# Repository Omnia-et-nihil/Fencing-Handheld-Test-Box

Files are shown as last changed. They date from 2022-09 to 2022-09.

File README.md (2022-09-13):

# Fencing-Handheld-Test-Box
Hardware and software overview: https://youtu.be/j7mpaZ8sDjs  
Functionality overview: https://youtu.be/PdIM2SgSRJE  
    
Assembly notes:  
If you choose to make the housing directly from the included files, you may need to make subtle changes based on the 3d printer/materials used. These were designed for printing on an Anycubic Photon S. 

The screen protector is very slightly to large for the screen opening, so that it may be snapped into place without requiring any other attatchment. It may be 3d printed with clear material using the included stl, or laser cut from clear acrylic using the included svg file.   
  
  The stls for the lid and screen protector include small rounded tabs for easier removal from a resin print plate. They help allow a shim(such as a flexible putty knife) to be slid under the print for relatively easy removal, and then may be easily cut off. 
  
  The tab stencil is an outline you can use to cut out some tabs out of your preferred sheet metal(though it should be uncoated so as to have a conductive surface). Fold the tabs in half around a dowel of some kind, and solder wires to the base before sliding into the slots on the front of the box.

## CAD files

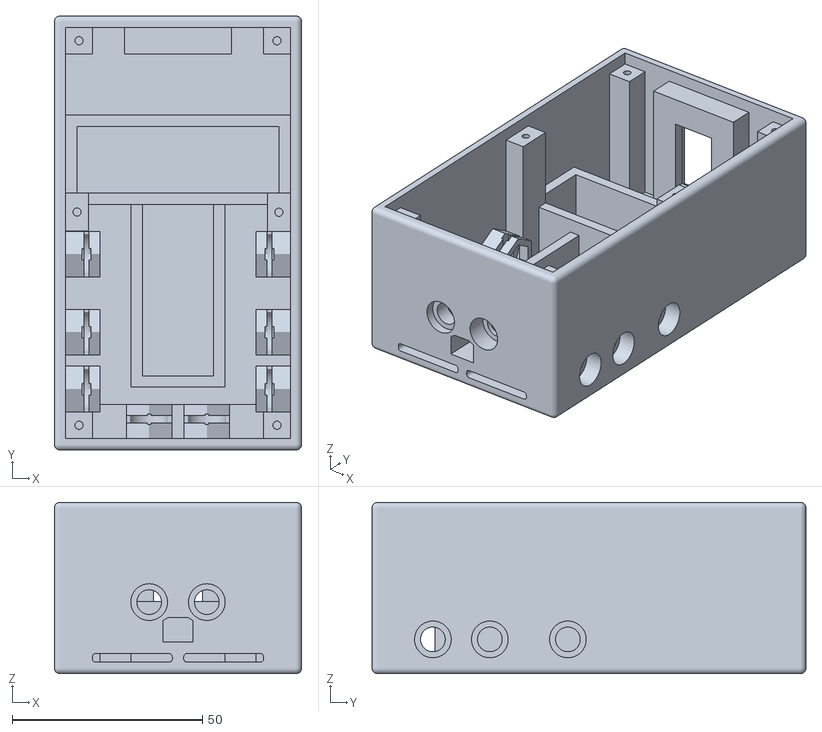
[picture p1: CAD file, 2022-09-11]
test box housing v5.1.stl
65.0 x 114.0 x 45.0

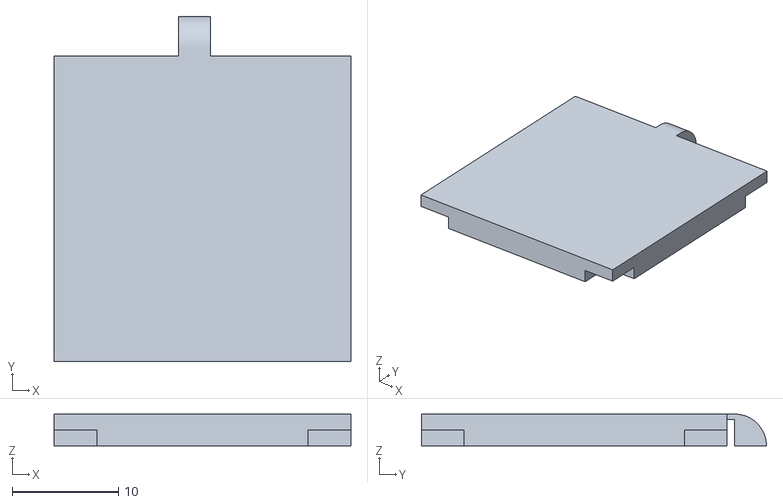
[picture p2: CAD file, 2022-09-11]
test box screen protector v5.1.stl
27.9 x 32.4 x 3.00

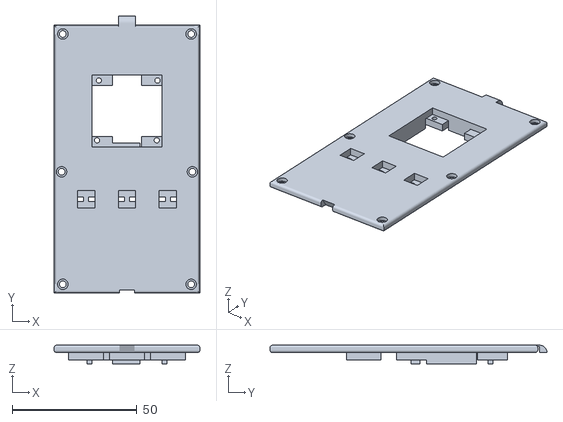
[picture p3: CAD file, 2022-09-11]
test box lid v5.1.stl
58.4 x 111.0 x 7.50

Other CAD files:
fencing test box.f3d

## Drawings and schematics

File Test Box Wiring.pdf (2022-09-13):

tsr | / I / | - socket 4%2^2224 :&"

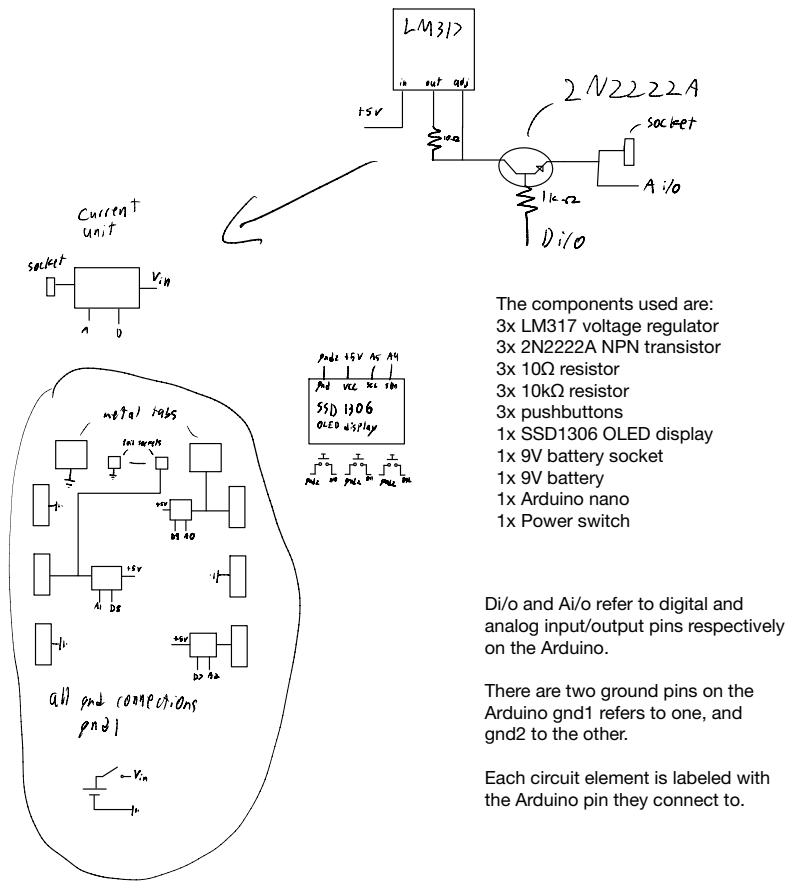
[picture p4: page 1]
out adj; current; unit; Dito; socket; Vin; 9ndzt5VA5A4; VCC; SDA; metal +93s; SSD 1306; 9hdz; gndz.DK; f-Vin

The components used are:
3x LM317 voltage regulator
3x 2N2222A NPN transistor
3x 10Ω resistor
3x 10kΩ resistor
3x pushbuttons
1x SSD1306 OLED display
1x 9V battery socket
1x 9V battery
1x Arduino nano
1x Power switch

OLED display foil sockets

Di/o and Ai/o refer to digital and
analog input/output pins respectively
on the Arduino.

all qnd connections
qndl

There are two ground pins on the
Arduino gnd1 refers to one, and
gnd2 to the other.

Each circuit element is labeled with
the Arduino pin they connect to.

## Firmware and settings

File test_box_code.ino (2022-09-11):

#include <SPI.h>
#include <Wire.h>
#include <Adafruit_GFX.h>
#include <Adafruit_SSD1306.h>
#include <EEPROM.h>

Adafruit_SSD1306 display(128, 64, &Wire, -1);

const unsigned char startGraphic [] PROGMEM = { //Bitmap for the initialization graphic.
  0x00, 0x00, 0x00, 0x00, 0x00, 0x00, 0x01, 0x38, 0x00, 0x00, 0x00, 0x00, 0x00, 0x00, 0x00, 0x00, 
  0x00, 0x00, 0x00, 0x00, 0x00, 0x00, 0x07, 0x78, 0x00, 0x00, 0x00, 0x00, 0x00, 0x00, 0x00, 0x00, 
  0x00, 0x00, 0x00, 0x00, 0x00, 0x00, 0x07, 0x78, 0x00, 0x00, 0x00, 0x00, 0x00, 0x00, 0x00, 0x00, 
  0x00, 0x00, 0x00, 0x00, 0x00, 0x00, 0x07, 0x78, 0x00, 0x00, 0x00, 0x00, 0x00, 0x00, 0x00, 0x00, 
  0x00, 0x00, 0x00, 0x00, 0x00, 0x00, 0x0f, 0x78, 0x00, 0x00, 0x00, 0x00, 0x00, 0x00, 0x00, 0x00, 
  0x00, 0x00, 0x00, 0x00, 0x00, 0x00, 0x0f, 0x78, 0x00, 0x00, 0x00, 0x00, 0x00, 0x00, 0x00, 0x00, 
  0x00, 0x00, 0x00, 0x00, 0x00, 0x00, 0x07, 0x78, 0x00, 0x00, 0x00, 0x00, 0x00, 0x00, 0x00, 0x00, 
  0x00, 0x00, 0x00, 0x00, 0x00, 0x00, 0x07, 0x78, 0x00, 0x00, 0x00, 0x00, 0x00, 0x00, 0x00, 0x00, 
  0x00, 0x00, 0x00, 0x00, 0x00, 0x00, 0x07, 0x78, 0x00, 0x00, 0x00, 0x00, 0x00, 0x00, 0x00, 0x00, 
  0x00, 0x00, 0x00, 0x00, 0x00, 0x00, 0x01, 0x00, 0x00, 0x00, 0x00, 0x00, 0x00, 0x00, 0x00, 0x00, 
  0x00, 0x00, 0x00, 0x00, 0x00, 0x00, 0x00, 0x00, 0x00, 0x00, 0x00, 0x00, 0x00, 0x00, 0x00, 0x00, 
  0x00, 0x00, 0x00, 0x00, 0x00, 0x00, 0x00, 0x00, 0xc0, 0x00, 0x00, 0x00, 0x00, 0x00, 0x00, 0x00, 
  0x00, 0x00, 0x00, 0x00, 0x00, 0x00, 0x00, 0x03, 0xf0, 0x00, 0x00, 0x00, 0x00, 0x00, 0x00, 0x00, 
  0x00, 0x00, 0x00, 0x00, 0x00, 0x0f, 0xfc, 0x07, 0xfc, 0x00, 0x00, 0x00, 0x00, 0x00, 0x00, 0x00, 
  0x00, 0x00, 0x00, 0x03, 0xbf, 0xff, 0xfc, 0x07, 0xff, 0x00, 0x00, 0x00, 0x00, 0x00, 0x00, 0x00, 
  0xff, 0xff, 0xff, 0xff, 0xff, 0xff, 0xfc, 0x07, 0xff, 0x80, 0x00, 0x00, 0x00, 0x00, 0x00, 0x00, 
  0x00, 0x00, 0x00, 0x03, 0xff, 0xff, 0xfe, 0x03, 0xff, 0xe0, 0x00, 0x00, 0x00, 0x00, 0x00, 0x00, 
  0x00, 0x00, 0x00, 0x01, 0x03, 0xff, 0xfe, 0x03, 0xff, 0xf8, 0x00, 0x00, 0x00, 0x00, 0x00, 0x00, 
  0x00, 0x00, 0x00, 0x00, 0x00, 0x00, 0x7e, 0x00, 0xff, 0xfc, 0x00, 0x00, 0x00, 0x00, 0x00, 0x00, 
  0x00, 0x00, 0x00, 0x00, 0x00, 0x00, 0x00, 0x00, 0x1f, 0xff, 0x00, 0x00, 0x00, 0x00, 0x00, 0x00, 
  0x00, 0x00, 0x00, 0x00, 0x00, 0x00, 0x00, 0x00, 0x07, 0xff, 0x80, 0x00, 0x00, 0x00, 0x00, 0x00, 
  0x00, 0x00, 0x00, 0x00, 0x00, 0x00, 0x00, 0x00, 0x00, 0xff, 0xc0, 0x00, 0x00, 0x00, 0x00, 0x00, 
  0x00, 0x00, 0x00, 0x00, 0x00, 0x00, 0x00, 0x00, 0x00, 0x1f, 0xf0, 0x00, 0x00, 0x00, 0x00, 0x00, 
  0x00, 0x00, 0x00, 0x00, 0x00, 0x00, 0x00, 0x00, 0x00, 0x07, 0xf8, 0x00, 0x00, 0x00, 0x00, 0x00, 
  0x00, 0x00, 0x00, 0x00, 0x00, 0x00, 0x00, 0x00, 0x00, 0x01, 0xfc, 0x00, 0x00, 0x00, 0x00, 0x00, 
  0x00, 0x00, 0x00, 0x00, 0x00, 0x00, 0x00, 0x00, 0x00, 0x00, 0x7f, 0x00, 0x00, 0x00, 0x00, 0x00, 
  0x00, 0x00, 0x00, 0x00, 0x00, 0x00, 0x00, 0x00, 0x00, 0x00, 0x1f, 0x80, 0x00, 0x00, 0x00, 0x00, 
  0x00, 0x00, 0x00, 0x00, 0x00, 0x00, 0x00, 0x1f, 0xe0, 0x00, 0x07, 0xc0, 0x00, 0x00, 0x00, 0x00, 
  0x00, 0x00, 0x00, 0x00, 0x00, 0x00, 0x00, 0xff, 0xf0, 0x00, 0x03, 0xe0, 0x00, 0x00, 0x00, 0x00, 
  0x00, 0x00, 0x00, 0x00, 0x00, 0x00, 0x07, 0xff, 0xf8, 0x00, 0x00, 0xc0, 0x00, 0x00, 0x00, 0x00, 
  0x00, 0x00, 0x00, 0x00, 0x00, 0x00, 0x3f, 0xff, 0xfc, 0x00, 0x00, 0x00, 0x00, 0x00, 0x00, 0x00, 
  0x00, 0x00, 0x00, 0x00, 0x00, 0x01, 0xff, 0xff, 0xfe, 0x00, 0x00, 0x00, 0x00, 0x00, 0x00, 0x00, 
  0x00, 0x00, 0x00, 0x00, 0x00, 0x03, 0xff, 0xff, 0xff, 0x00, 0x00, 0x00, 0x00, 0x00, 0x00, 0x00, 
  0x00, 0x00, 0x00, 0x00, 0x00, 0x07, 0xff, 0xff, 0xff, 0x80, 0x00, 0x00, 0x00, 0x00, 0x00, 0x00, 
  0x00, 0x00, 0x00, 0x00, 0x00, 0x07, 0xff, 0xff, 0xff, 0xc0, 0x00, 0x00, 0x00, 0x00, 0x00, 0x00, 
  0x00, 0x00, 0x00, 0x00, 0x00, 0x07, 0xff, 0xff, 0xff, 0xe0, 0x00, 0x00, 0x00, 0x00, 0x00, 0x00, 
  0x00, 0x00, 0x00, 0x00, 0x00, 0x0f, 0xff, 0xe1, 0xff, 0xf0, 0x00, 0x00, 0x00, 0x00, 0x00, 0x00, 
  0x00, 0x00, 0x00, 0x00, 0x00, 0x0f, 0xc0, 0x00, 0x7f, 0xf8, 0x00, 0x00, 0x00, 0x00, 0x00, 0x00, 
  0x00, 0x00, 0x00, 0x00, 0x00, 0x0f, 0xc0, 0x00, 0x3f, 0xfc, 0x00, 0x00, 0x00, 0x00, 0x00, 0x00, 
  0x00, 0x00, 0x00, 0x00, 0x00, 0x0f, 0x80, 0x00, 0x0f, 0xfe, 0x00, 0x00, 0x00, 0x00, 0x00, 0x00, 
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
};

const int rightButton = 10; //Pin assignments for the navigation buttons: left, select, and right.
const int selButton = 11;
const int leftButton = 12;

const int aLine = A1; //Analog pin assignments for the cord lines. Will read the voltage on their respective sockets. 
const int bLine = A2;
const int cLine = A3;

const int aVoltage = 9; //Digital pin assignments for the cord lines. Used to enable/disable the constant current through the line via transistors. 
const int bVoltage = 8;
const int cVoltage = 7;


int leftButtonState;             //Variables used in the debounce code.
int lastLeftButtonState = HIGH;
int selButtonState;
int lastSelButtonState = HIGH;
int rightButtonState;
int lastRightButtonState = HIGH;  
bool leftTemp;
bool leftReturn;
bool selTemp;
bool selReturn;
bool rightTemp;
bool rightReturn;
unsigned long lastLeftDebounceTime = 0;
unsigned long lastSelDebounceTime = 0;
unsigned long lastRightDebounceTime = 0;  
unsigned long debounceDelay = 50;   

int aVals[] = {0,0,0,0,0,0,0,0,0,0,0,0,0,0,0,0,0,0,0,0,0,0,0,0}; //Initialization of arrays of readings of the resistance, non-linearly scaled, to be more sensitive to lower measurements. 
int bVals[] = {0,0,0,0,0,0,0,0,0,0,0,0,0,0,0,0,0,0,0,0,0,0,0,0};
int cVals[] = {0,0,0,0,0,0,0,0,0,0,0,0,0,0,0,0,0,0,0,0,0,0,0,0};

bool ab; //Initialization of variables used for the cross-connection test. 
bool bc;
bool ac;

const int homepage = 0; //Definition of page numbers. These are used to keep track of which menu page and associated functions should be run.  
const int cordpage = 1;
const int bladepage = 2;
const int crosspage = 3;
const int lamepage = 4;
const int settings = 5;
const int setTests = 6;
const int confirmSet = 7;
const int zeropage = 8;
const int calibrate = 9;

int page = homepage;
int testpage = cordpage;
int lastpage = cordpage;

bool cordOn = true; //State variables determining whether each page is enabled or disabled by default when the device is powered on.
bool bladeOn = true;
bool crossOn = true;
bool lameOn = true;
bool zeroOn = true;


bool graphOrText = false; //State variable determining whether the resistance values are gaphed, or text is shown corresponding to certain value ranges. 

int line = 0;      //Variables for the highlight function used in menu pages. "line" tracks which line is currently highlighted.
int lineShift = 0; //For pages with more than three lines, lineShift keeps track of the offset as the pages are navigated, so that the correct three lines are always displayed.

const char tests0[] = " Cord"; //Due to memory issues involoving how the display handles strings, some of the text needs to be stored in this way to prevent glitching. 
const char tests1[] = " Zero";
const char tests2[] = " Blade";
const char tests3[] = " Cross";
const char tests4[] = " Lame";
const char tests5[] = " Back";

const char *tests[]  = {tests0,tests1,tests2,tests3,tests4,tests5};
const char *settingsGraph[] = {" Tests"," Graph"," Set"," Home"};
const char *settingsText[] = {" Tests"," Text"," Set"," Home"};

const int testAddress = 0;    //EEPROM memory addresses used to store settings through power cycles.
const int graphAddress = 1;
const int cordAddress = 2;
const int bladeAddress = 3;
const int crossAddress = 4;
const int lameAddress = 5;
const int zeroAddress = 6;

float aVal; //Variables use in the measurement functions.
float bVal;
float cVal;

float ra0 = 0.0; //variables used in the zeroing function, where the values are subtracted from the final resistance calculation to account for cord resistance when measuring blade resistances. 
float rb0 = 0.0;
float rc0 = 0.0;

const float aCurrent = .076; //Constant currents produced by the sources. 
const float bCurrent = .148;
const float cCurrent = .084;

float sum; //Used in the measurement functions for averaging readings. 

const float maxVal = 25.0; //Setting a maximum resistance value. Anything higher than 25 will read as 25. 

const float inc = 0.26; // Value used in the parabolic scaling function for the resistance vs time graph. 

int aText = 2; //More memory tricks to stop the display from glitching. 
int bText = 2;
int cText = 2;
const char *texts[3] = {"Good","Iffy","Bad"};

bool readLeft() {                                          //Debouncing function that reads the left button.
  int leftReading = digitalRead(leftButton);
  if(leftReading == HIGH){
    lastLeftDebounceTime = millis();
    leftReturn = true;
  }
  if(millis() - lastLeftDebounceTime > debounceDelay){
    if(leftReturn){
      leftTemp = true;
      leftReturn = false;
    }else{
      leftTemp = false;
    }
  }else{
    leftTemp = false;
  }
  lastLeftButtonState = leftReading;
  return leftTemp;
}

bool readSel() {                                           //Debouncing function that reads the center button.
  int leftReading = digitalRead(leftButton);
  int selReading = digitalRead(selButton);
  if(selReading == HIGH){
    lastSelDebounceTime = millis();
    selReturn = true;
  }
  if(millis() - lastSelDebounceTime > debounceDelay){
    if(selReturn){
      selTemp = true;
      selReturn = false;
    }else{
      selTemp = false;
    }
  }else{
    selTemp = false;
  }
  lastSelButtonState = selReading;
  return selTemp;
}

bool readRight() {                                         //Debouncing function that reads the right button.
  int leftReading = digitalRead(leftButton);
  int rightReading = digitalRead(rightButton);
  if(rightReading == HIGH){
    lastRightDebounceTime = millis();
    rightReturn = true;
  }
  if(millis() - lastRightDebounceTime > debounceDelay){
    if(rightReturn){
      rightTemp = true;
      rightReturn = false;
    }else{
      rightTemp = false;
    }
  }else{
    rightTemp = false;
  }
  lastRightButtonState = rightReading;
  return rightTemp;
}

void highlight(){                                          //Inverts the display for a given line of text.
  if(line != 0){
    for(int y = 16 * line; y < 16 * line + 14; y++){
      display.drawLine(0,y,127,y,2);
    }
  }
}


void initializeHomepage(){                                 //Initialization function for the homepage. 
  display.clearDisplay();                                  //Starts by clearing the display,then setting the cursor position and text color. 
  display.setCursor(0,0);
  display.setTextColor(1);
  display.println(" Home");                                //Begins writing text from the cursor's position(top right corner of the screen)
  display.println(" Test");
  display.println(" Settings");
  display.display();                                       //No changes made to what is shown on the display will take effect until this is called.
  line = 0;                                                //The "line" variable controls which line(other than 0) will be inverted with the highlight function. 
  lastpage = homepage;                                     //The "lastpage" variable, and setting it to "homepage" here, are used to ensure that this function is only called when switching to the homepage.
}

void Homepage(){               //This function will be run over and over as long as the current page is the homepage.
  if(lastpage != homepage){    //Ensuring the the initialization function only runs when the page has been changed to homepage from something else.
    initializeHomepage();
  }
  while(page == homepage){                                 
    if(readRight()){          //Checking to see if the right button has been pressed. 
      highlight();            //If so, the currently highlighted line is inverted back to normal. 
      line++;                 //The "line" value is increased by 1.
      if(line == 3){          //The homepage only has two lines, so 3 is cycled back to 1(line 0 is for the page name, so there is no need to select and highlight it).
        line = 1;
      }
      highlight();            //The newly selected line is now highlighted. 
      display.display();      //And displayed. 
    }
    if(readLeft()){           //This does the same thing as readRight, just decreasing line instead of increasing it.
      highlight();
      line--;
      if(line < 1){
        line = 2;
      }
      highlight();
      display.display();
    }
    if(readSel()){            //If the select button is pressed, the page is changed to whichever one corresponds to the text on that line.
      if(line == 1){
        page = testpage;     //"testpage" is not a constant value. It is set to one of the test page values, thus keeping track of the last test page, which will be the first one loaded from the homepage.
      }
      if(line == 2){
        page = settings;     //The other page that can be acessed directly from the homepage is the settings. 
      }
    }
  }
}

String GraphOrText(){    //Used in the settings to show whether the resistance graph or text will be displayed.
  if(graphOrText){
    return " Graph";
  }else{
    return " Text";
  }
}



void printSettings(){ //The settings page has more than three lines of options, so this function prints the correct three based on which line is selected, as well as the current offset from "lineShift"
  display.clearDisplay();
  display.setTextColor(1);
  display.setCursor(0,0);
  display.println(" Settings");
  if(graphOrText){
    for(int i = 0; i < 3; i++){
      display.println(settingsGraph[i + lineShift]);
    }
  }else{
    for(int i = 0; i < 3; i++){
      display.println(settingsText[i + lineShift]);
    }
  }
}

void initializeSettings(){ //Initialization function for the settings page. 
  line = 0;
  lineShift = 0;
  display.clearDisplay();
  display.setCursor(0,0);
  display.setTextColor(1);
  printSettings();
  display.display();
  lastpage = settings;
}

void Settings(){   //Settings page function.
  if(lastpage != settings){ 
    initializeSettings();
  }
  while(page == settings){
    if(readRight()){           //Using the lineshift to scroll the highlight and the three displayed lines.
      highlight();
      if(line == 3){
        if(lineShift < 1){
          lineShift++; 
          printSettings();
          highlight();
          display.display();
        }else{
          lineShift = 0;
          line = 1;
          printSettings();
          highlight();
          display.display();
          }
      }else{
        line++;
        highlight();
        display.display();
      }
    }
    if(readLeft()){
    highlight();
    if(line < 2){
      if(lineShift > 0){
        lineShift--;
        printSettings();
        highlight();
        display.display();
      }else{
        lineShift = 1;
        line = 3;
        printSettings();
        highlight();
        display.display();
      }
    }else{
      line--;
      highlight();
      display.display();
    }
   }
    
    if(readSel()){
      switch(line + lineShift){
        case 0:
        page = homepage;          //Back to the homepage Line zero is where the highlight starts when a page is first opened, but doesn't actually highlight anything and can't be scrolled back to.
        break;
      
        case 1:
        page = setTests;          //To the setTests page
        break;

        case 2:
        graphOrText = !graphOrText; //Toggles the state of the graphOrText boolean and then refreshes the display to display the changed state.
        printSettings();
        highlight();
        display.display();
        break;

        case 3:
        page = confirmSet;          //To the confirmSet page
        break;

        case 4:
        page = homepage; //Another back to homepage. Since line zero cannot be scrolled back to this line is added to provide an additional back to home. This is done for aesthetic preferences for the UI. 
        break;
      }
    }
  }
}

void Set(){ //Stores the current settings in EEPROM memory.
  EEPROM.update(testAddress,testpage);
  EEPROM.update(graphAddress,graphOrText);
  EEPROM.update(cordAddress,cordOn);
  EEPROM.update(bladeAddress,bladeOn);
  EEPROM.update(crossAddress,crossOn);
  EEPROM.update(lameAddress,lameOn);
  EEPROM.update(zeroAddress,zeroOn);
}

void initializeConfirmSet(){ //Initialization for the confirm set page.
  display.clearDisplay();
  display.setTextColor(1);
  display.setCursor(0,0);
  display.println(" Confirm");
  display.println(" Yes");
  display.println(" No");
  display.display();
  lastpage = confirmSet;
  line = 0;
}

void ConfirmSet(){
  if(lastpage != confirmSet){
    initializeConfirmSet();
  }
  while(page == confirmSet){ //Navigation between the two lines: "Yes" and "No"
    if(readRight()){
      highlight();
      line++;
      if(line > 2){
        line = 1;
      }
      highlight();
      display.display();
    }
    if(readLeft()){
      highlight();
      line--;
      if(line < 1){
        line = 2;
      }
      highlight();
      display.display();
    }
    if(readSel()){  //When the select button is pressed it returns to the homepage if "No" or line 0 was selected. If "Yes" was selected the settings are stored in EEPROM before returning to the homepage. 
      if(line == 1){
        Set();
      }
      page = homepage;
    }
  }
}

void printTestTicks(){  //This is used in the setTests page to show which of the testing pages are enabled/disabled. 
  if(lineShift == 0){
    display.drawChar(74,16,0x04,cordOn,0,2);
    display.drawChar(74,32,0x04,zeroOn,0,2);
    display.drawChar(74,48,0x04,bladeOn,0,2);
  }
  if(lineShift == 1){
    display.drawChar(74,16,0x04,zeroOn,0,2);
    display.drawChar(74,32,0x04,bladeOn,0,2);
    display.drawChar(74,48,0x04,crossOn,0,2);
  }
  if(lineShift == 2){
    display.drawChar(74,16,0x04,bladeOn,0,2);
    display.drawChar(74,32,0x04,crossOn,0,2);
    display.drawChar(74,48,0x04,lameOn,0,2);
  }
  if(lineShift == 3){
    display.drawChar(74,16,0x04,crossOn,0,2);
    display.drawChar(74,32,0x04,lameOn,0,2);
  }
}

void printTestLines(){  //Prints the appropriate lines of text based on the lineShift offset.
  display.clearDisplay();
  display.setTextColor(1);
  display.setCursor(0,0);
  display.println(" Set Tests");
  display.println(tests[0 + lineShift]);
  display.println(tests[1 + lineShift]);
  display.println(tests[2 + lineShift]);
}

void initializeSetTests(){ //Initialization.
  line = 0;
  lineShift = 0;
  printTestLines();
  printTestTicks();
  display.display();
  line = 0;
  lastpage = setTests;
}
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
void loop(){ //checks what the current page is and runs the apropriate function, which will therefore run every iteration of the loop until the page is changed. 
  switch(page){
    case homepage:
    Homepage();
    break;

    case settings:
    Settings();
    break;

    case setTests:
    SetTests();
    break;

    case confirmSet:
    ConfirmSet();
    break;

    case cordpage:
    Cordpage();
    break;

    case zeropage:
    zero();
    break;

    case bladepage:
    Bladepage();
    break;

    case crosspage:
    Crosspage();
    break;

    case lamepage:
    Lamepage();
    break;
  }
}

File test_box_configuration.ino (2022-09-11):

#include <EEPROM.h>

const int cordpage = 1; //Defining the variables to be set. Technically they don't need to be laid out here, but this format makes it easier to make and follow changes if desired.
const int bladepage = 2;
const int crosspage = 3;
const int lamepage = 4;

const int testAddress = 0;
const int graphAddress = 1;
const int cordAddress = 2;
const int bladeAddress = 3;
const int crossAddress = 4;
const int lameAddress = 5;
const int zeroAddress = 6;

//Different functions are defined to set different presets.

void configureA(){ //Sets the default test page to cord, enables all test pages, and enables the graph vs text.
  EEPROM.update(testAddress, cordpage);
  EEPROM.update(graphAddress, true);
  EEPROM.update(cordAddress, true);
  EEPROM.update(bladeAddress, true);
  EEPROM.update(crossAddress, true);
  EEPROM.update(lameAddress, true);
  EEPROM.update(zeroAddress, true);
}

void configureB(){ //Sets the default test page to cord, enables all test pages except zero, and enables the text vs graph.
  EEPROM.update(testAddress, cordpage);
  EEPROM.update(graphAddress, false);
  EEPROM.update(cordAddress, true);
  EEPROM.update(bladeAddress, true);
  EEPROM.update(crossAddress, true);
  EEPROM.update(lameAddress, true);
  EEPROM.update(zeroAddress, false);
}

void setup(){
  Serial.begin(9600);
  configureA(); //Sets to the desired preset. 
  Serial.print("Test: "); //Prints the EEPROM values to confirm successful configuration.
  Serial.println(EEPROM.read(testAddress));
  Serial.print("Graph: ");
  Serial.println(EEPROM.read(graphAddress));
  Serial.print("Cord: ");
  Serial.println(EEPROM.read(cordAddress));
  Serial.print("Blade: ");
  Serial.println(EEPROM.read(bladeAddress));
  Serial.print("Cross: ");
  Serial.println(EEPROM.read(crossAddress));;
  Serial.print("Lame: ");
  Serial.println(EEPROM.read(lameAddress));
  Serial.print("Set Blade: ");
  Serial.println(EEPROM.read(zeroAddress));
}

void loop(){
}
